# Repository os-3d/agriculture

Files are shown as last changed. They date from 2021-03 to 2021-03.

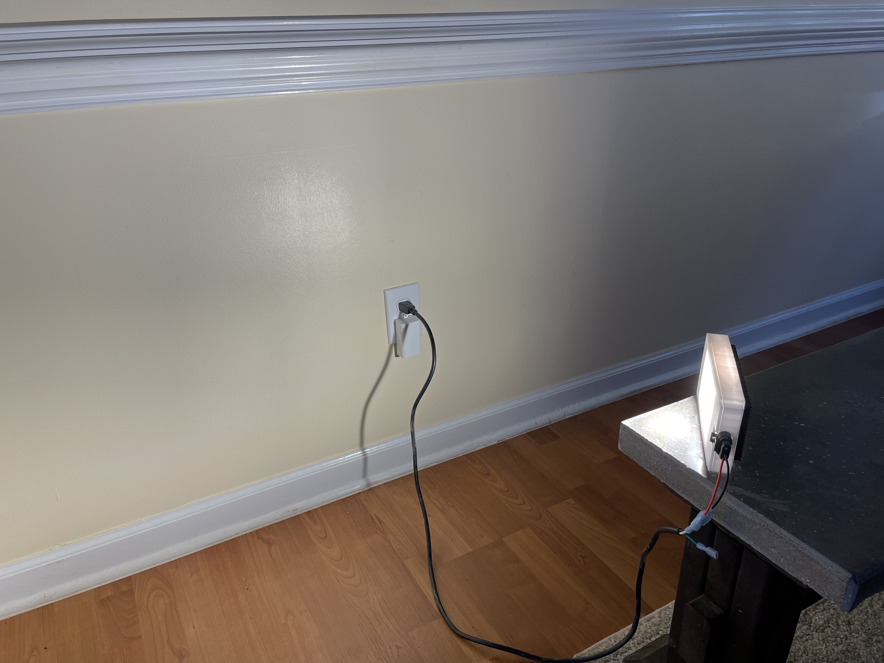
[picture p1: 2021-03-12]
01_lighting/chip_light_1.0/images/chip_light_1.0_output.jpg

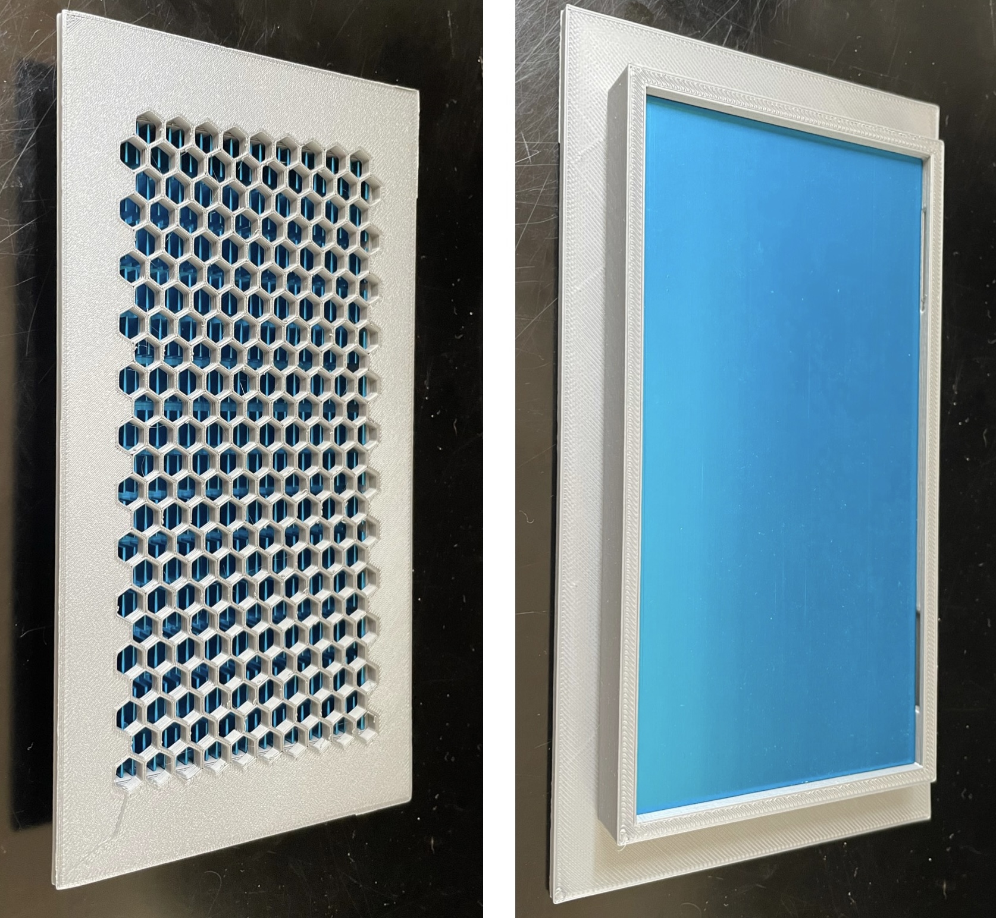
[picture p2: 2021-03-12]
01_lighting/chip_light_2.0/images/chip_light_modular_upper.jpg

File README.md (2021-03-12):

# Open Source Agriculture
The scope of this work is defined as:

1. Lighting Control
2. Growth Medium Control
3. Water Management
4. Mineral/Nutrient Management

This project touches on 3 of the fourteen NAE engineering grand challenges:

1. Manage the Nitrogen Cycle - To restore balance to the nitrogen cycle with better fertilization technologies and by capturing and recycling waste.
2. Develop Carbon Sequestration Methods - Working on ways to capture and store excess carbon dioxide to prevent global warming.
3. Engineer the Tools of Scientific Discovery - Continue to be partners with scientists in the great quest for understanding many unanswered questions of nature.

Taking this a step further, the primary goals of this project are: to enable direct research into the optimization of food-production systems, and to take the tools and information that are devleoped and put it in the hands of anyone who wants it.

Included are the object primitives and/or gcode files to support independent research into agricultural best practices.

<br />This work is licensed under a <a rel="license" href="http://creativecommons.org/licenses/by-nc-sa/4.0/">Creative Commons Attribution-NonCommercial-ShareAlike 4.0 International License</a>.

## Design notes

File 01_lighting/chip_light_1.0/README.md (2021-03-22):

# Chip Light 1.0

# Disclosure
1. Potential (severe) burn risk.
2. Potential (severe, life threatening) electrical shock risk from working with electrical outlet level voltage/amps.

*Note: Exercise all appropriate caution when designing/building/using hot objects (electrical or otherwise). 

# Print Characteristics
1. Prusa MK3S+ 3D Printer
2. Filament: White PLA+ (~ $2 worth)
3. Nozzle: 0.4mm
4. Initial Layer Temp: 235 C
5. Layer Temp: 220 C
6. Infill: 20%
7. Quality: Draft (0.3mm layer hieght)
8. Support/Brim: None

# Features
1. Passive Cooling
2. Light Diffusing
3. Quick Connect System

# Additional Items List
1. 50W Full Spectrum LED COB with integrated 120v AC to DC controller ($11)
2. Aluminium heatsink 150mm (L) x 70mm (W) x10mm (H) ($11)
3. COB LED lens, 90 degree, size: 75x40mm ($14)
4. 125v 10A switch ($1)
5. 16 AWG solid-core wire (< $0.50)
6. Waterproof electrical connector, 16 AWG 3 pin ($2.60)
7. Silicon adhesive (< $0.50)
8. Insulated crimp terminals (< $0.50)

# Results
1. Testing of the heatsink center and boundary temperature was conducted hourly for a period of 12 straight hours. After ramp up, the temperature gradient was consistent over this time and ranged from 53 degrees C (center) to 42 degrees C (boundary). The extrude temperature of PLA+ is 190 to 230 degrees C, so this is well within the material threshold to minimize melt or fire risk, though it does present a potential (severe) burn risk given the heatsink is exposed.
2. Light output and coverage is more than sufficient for (many) single-plant growth needs at a range of distances.

# Images

**Internal Construction**
chip_light_1 0_open

**Assembled Top View**
chip_light_1 0_top

**Light Output**
chip_light_1 0_output

# Next Steps
1. Design a solution that covers the heatsink.

# CC-BY-NC-SA License Extension
DESIGNS FOR Chip Light 1.0 ARE PROVIDED "AS IS", WITHOUT WARRANTY OF ANY KIND, EXPRESS OR IMPLIED, INCLUDING BUT NOT LIMITED TO THE WARRANTIES OF MERCHANTABILITY, FITNESS FOR A PARTICULAR PURPOSE AND NONINFRINGEMENT. IN NO EVENT SHALL THE CONTRIBUTORS OR COPYRIGHT HOLDERS BE LIABLE FOR ANY CLAIM, DAMAGES OR OTHER LIABILITY, WHETHER IN AN ACTION OF CONTRACT, TORT OR OTHERWISE, ARISING FROM, OUT OF OR IN CONNECTION WITH THE Chip Light 1.0 DESIGN OR THE USE OR OTHER DEALINGS WITH THE Chip Light 1.0 DESIGN.

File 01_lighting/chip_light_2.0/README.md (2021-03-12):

# Chip Light 2.0 - Work in Progress

# Disclosure
1. Potential (severe) burn risk.
2. Potential (severe, life threatening) electrical shock risk from working with electrical outlet level voltage/amps.

*Note: Exercise all appropriate caution when designing/building/using hot objects (electrical or otherwise). 

# Print Characteristics (Example Images)
1. Printer: Prusa MK3S+
2. Filament: PLA+
3. Nozzle: 0.4mm
4. Initial Layer Temp: 235 C
5. Layer Temp: 220 C
6. Infill: 25%
7. Quality: Draft (0.3mm layer height)
8. Support/Brim: None

# Features
1. Passive Cooling
2. Light Diffusing
3. Quick Connect System

# Additional Items List
1. 50W Full Spectrum LED COB with integrated 120v AC to DC controller 
2. Aluminium heatsink 150mm (L) x 74mm (W) x 10mm (H)

# Results
1.

# Next Steps
1. 

# CC-BY-NC-SA License Extension
DESIGNS FOR Chip Light 2.0 ARE PROVIDED "AS IS", WITHOUT WARRANTY OF ANY KIND, EXPRESS OR IMPLIED, INCLUDING BUT NOT LIMITED TO THE WARRANTIES OF MERCHANTABILITY, FITNESS FOR A PARTICULAR PURPOSE AND NONINFRINGEMENT. IN NO EVENT SHALL THE CONTRIBUTORS OR COPYRIGHT HOLDERS BE LIABLE FOR ANY CLAIM, DAMAGES OR OTHER LIABILITY, WHETHER IN AN ACTION OF CONTRACT, TORT OR OTHERWISE, ARISING FROM, OUT OF OR IN CONNECTION WITH THE Chip Light 2.0 DESIGN OR THE USE OR OTHER DEALINGS WITH THE Chip Light 2.0 DESIGN.

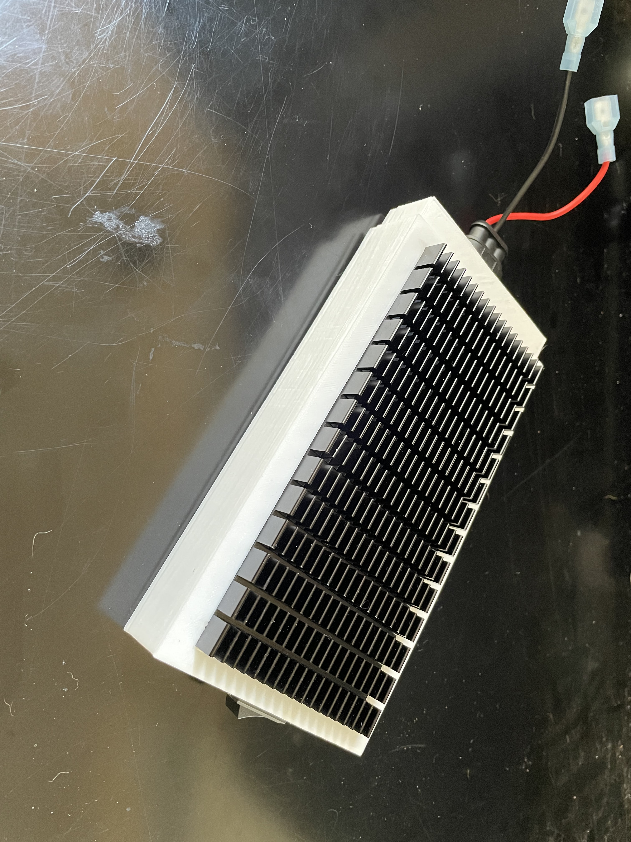
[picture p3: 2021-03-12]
01_lighting/chip_light_1.0/images/chip_light_1.0_top.jpg

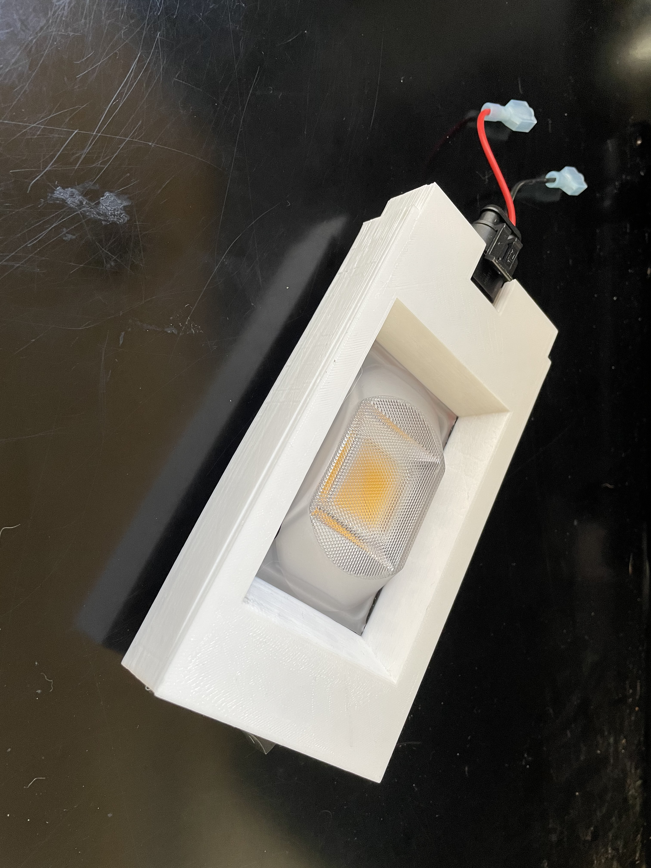
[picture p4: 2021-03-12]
01_lighting/chip_light_1.0/images/chip_light_1.0_bottom.jpg

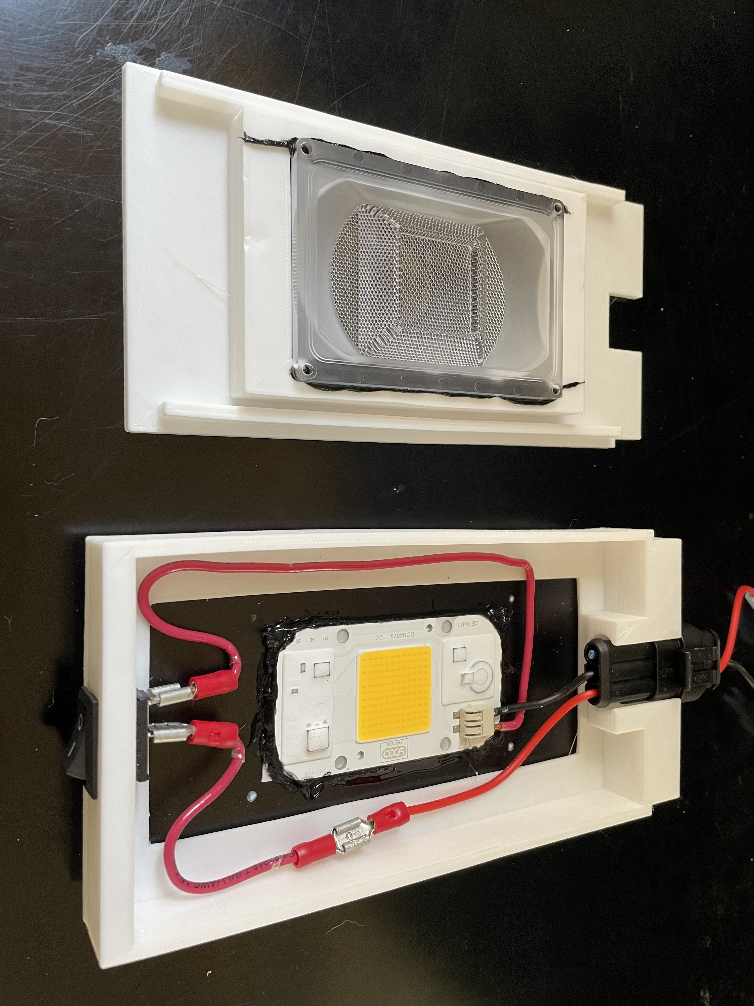
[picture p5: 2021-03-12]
01_lighting/chip_light_1.0/images/chip_light_1.0_open.jpg

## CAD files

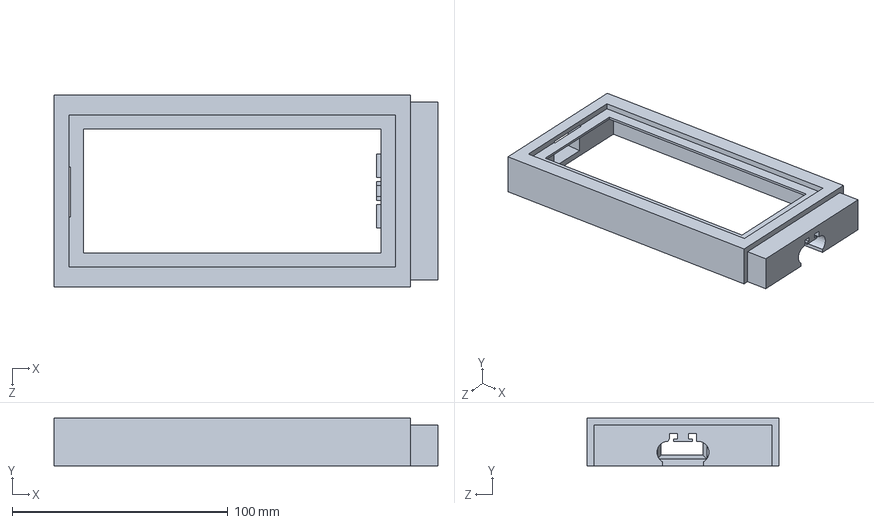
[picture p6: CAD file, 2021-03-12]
01_lighting/chip_light_1.0/solidworks/led_chip_light_upper.SLDPRT
177.8 x 22.2 x 88.9 mm

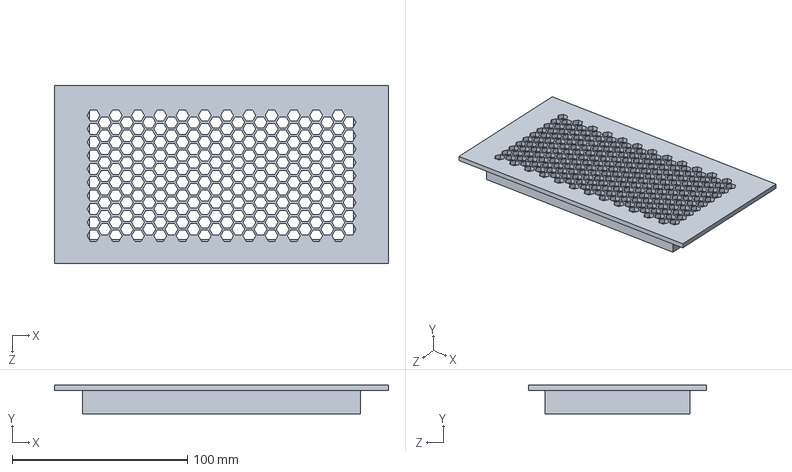
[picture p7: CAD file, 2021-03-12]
01_lighting/chip_light_2.0/solidworks/chip_light_modular_upper.SLDPRT
190.5 x 16.5 x 101.6 mm

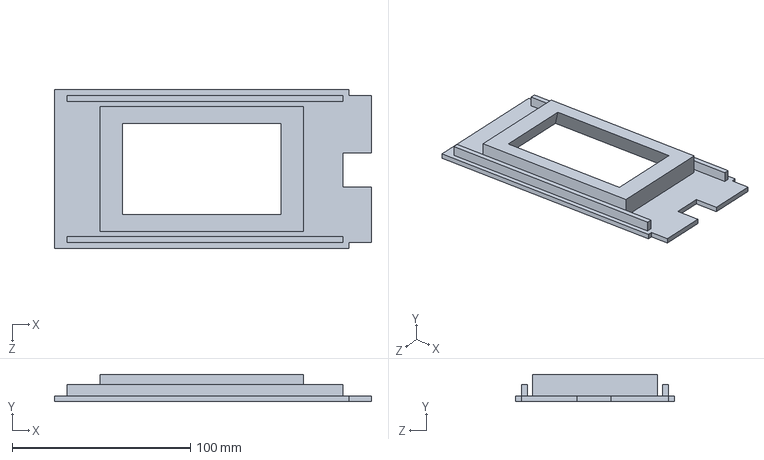
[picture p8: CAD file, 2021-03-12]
01_lighting/chip_light_1.0/solidworks/led_chip_light_lower.SLDPRT
177.8 x 15.2 x 88.9 mm

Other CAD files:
01_lighting/chip_light_1.0/stl/led_chip_light_lower.STL
01_lighting/chip_light_1.0/stl/led_chip_light_upper.STL
01_lighting/chip_light_2.0/stl/chip_light_modular_upper.STL
